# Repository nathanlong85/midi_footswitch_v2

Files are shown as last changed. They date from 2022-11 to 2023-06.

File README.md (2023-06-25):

# MIDI Footswitch v2

## The General Idea

The idea behind this is to be a customizable, solid footswitch for sending and receiving MIDI commands via USB. The following buttons will be implemented:

| Button | Count | Function |
|---|---|---|
| MIDI PC  | 5 | Send a Program Change MIDI command to switch between presets, snapshots, etc. |
| MIDI CC  | 6 | Send a Control Change MIDI command to switch pedals on/off |
| PC StepDown | 1 | Lower the range of PC numbers corresponding with the buttons (e.g. 6-10 to 1-5) |
| PC StepUp | 1 | Raise the range of PC numbers corresponding with the buttons (e.g. 1-5 to 6-10) |
| TempoTap | 1 | This'll probably just end up being a CC button |

The main purpose of this footswitch is to control guitar plugins and presets, specifically in LiveProfessor, but the MIDI out features should all still work fine in another program. Additionally, the footswitch accepts MIDI input. This allows LiveProfessor to send (for example) CC commands when switching presets that will control the button states and have them match up with the plugin states in the preset.

For example, if I switch to a preset that has only a TS808 plugin enabled, the footswitch will first switch all CC buttons off. Then LiveProfessor can send a CC command back to the footswitch to let it know that the button that corresponds with the TS808 should be on.

## Components Used

| Type | Count | Brand | Model | Link | Notes |
|---|---|---|---|---|---|
| Arduino | 1 | Elegoo | Mega2560 | | Chosen for the large number of pins available for buttons |
| Connections Board | 1 | Custom | N/A | N/A | Mostly a convenience to make things as modular as possible. Also used in place of a breadboard for components such as resistors for the LEDs and switches |
| Display | 1 | Teyleten Robot | 2.42" 128x64 SSD1309 OLED | https://a.co/d/j11dIGv | Connected via SPI |
| LED | 14 | N/A | N/A | N/A | Red 5mm |
| LED Holder | 14 | DaierTek | 5MM LED Lamp Holder | https://a.co/d/9saOy9M | |
| SD Card Module | 1 | HiLetgo | Micro SD TF Card Adater Reader Module | https://a.co/d/amf9kn3 | Connected via SPI |
| SD Card | 1 | | | | No need for a high capacity as the only things being stored are configs |
| FootSwitch | 14 | ESUPPORT | Momentary SPST Button | https://a.co/d/4z8qo4Z | |
| TSR Jack | 1 | Kingsing | N/A | https://a.co/d/iaOluce | For the expression pedal |
| Switch | 1 | uxcell | SS12F32-G7 | https://a.co/d/9ZpxkgF | Mini slider switch to change USB modes from Midi to Arduino for uploads |
| USB Jack | 1 | QIANRENON | N/A | https://a.co/d/0RwaqkX | USB-A to USB-C converter and passthrough plate |

Additionally, various electrical components, connector wires, header pins, etc. were used. Those should be available in the KiCad schematics.

## Arduino Pin Assignments

| Number | Purpose | Notes |
|---|---|---|
| 2 | SD Card SPI - CS | Ran out of pins to use near the other SPI pins |
| 22-26 | MIDI PC Button LEDs | Bottom row: buttons 1-5 |
| 27 | StepDown Button LED | Bottom row: button 6 |
| 28 | StepUp Button LED | Bottom row: button 7 |
| 29 | TempoTap Button LED | Bottom row: button 8 |
| 30-35 | MIDI CC Button LEDs | Top row: buttons 1-6 |
| 36-40 | MIDI PC Button Switches | Bottom row: buttons 1-5 |
| 41 | StepDown Button Switch | Bottom row: button 6 |
| 42 | StepUp Button Switch | Bottom row: button 7 |
| 43 | TempoTap Button Switch | Bottom row: button 8 |
| 44-49 | MIDI CC Button Switches | Top row: buttons 1-6 |
| 50 | SPI - MISO | Dictated by Arduino board |
| 51 | SPI - MOSI | Dictated by Arduino board |
| 52 | SPI - SCK | Dictated by Arduino board |
| 53 | Display SPI - CS | Conventional pin for first SPI device |

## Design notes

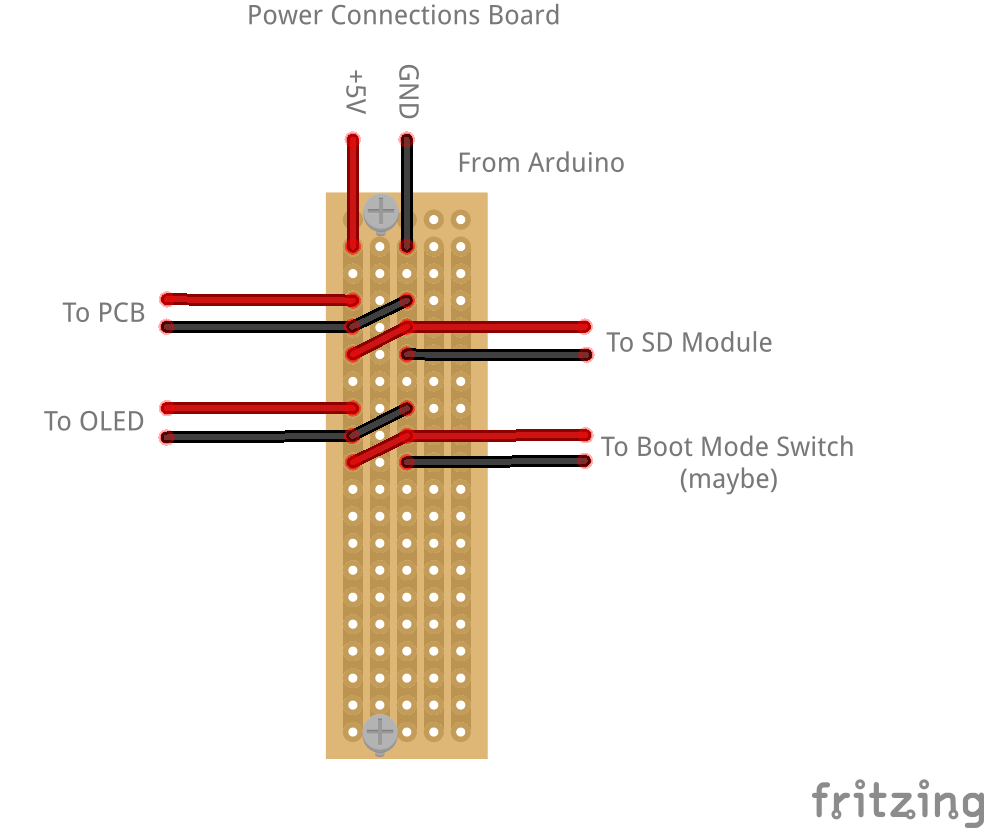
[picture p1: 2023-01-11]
docs/Stripboard Layouts/power_connections.png

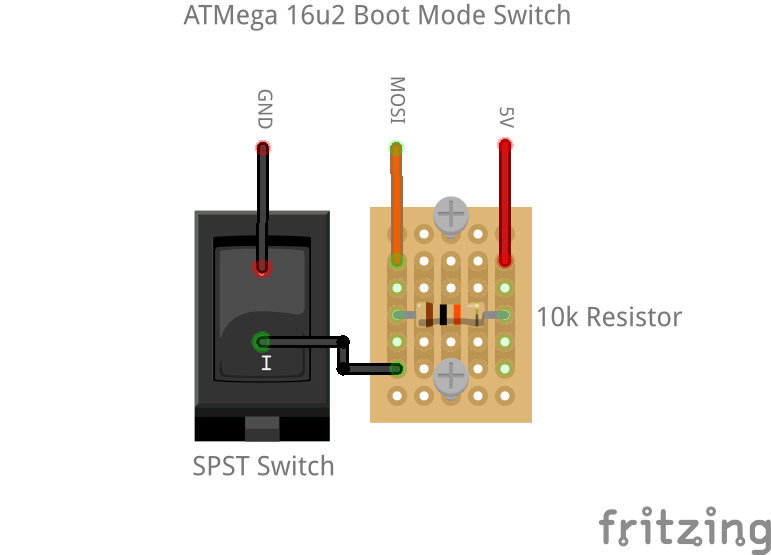
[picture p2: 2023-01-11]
docs/Stripboard Layouts/boot_mode_switch.png

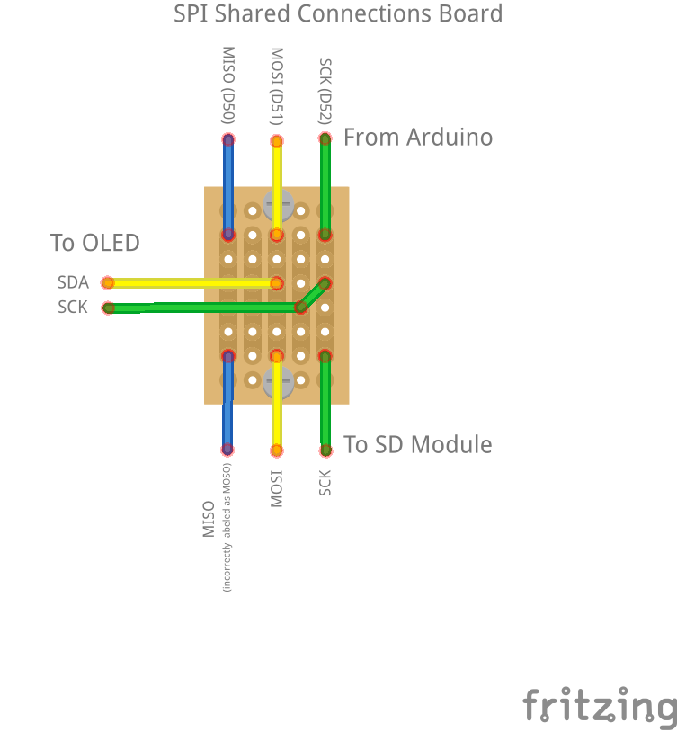
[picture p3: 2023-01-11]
docs/Stripboard Layouts/spi_connections.png

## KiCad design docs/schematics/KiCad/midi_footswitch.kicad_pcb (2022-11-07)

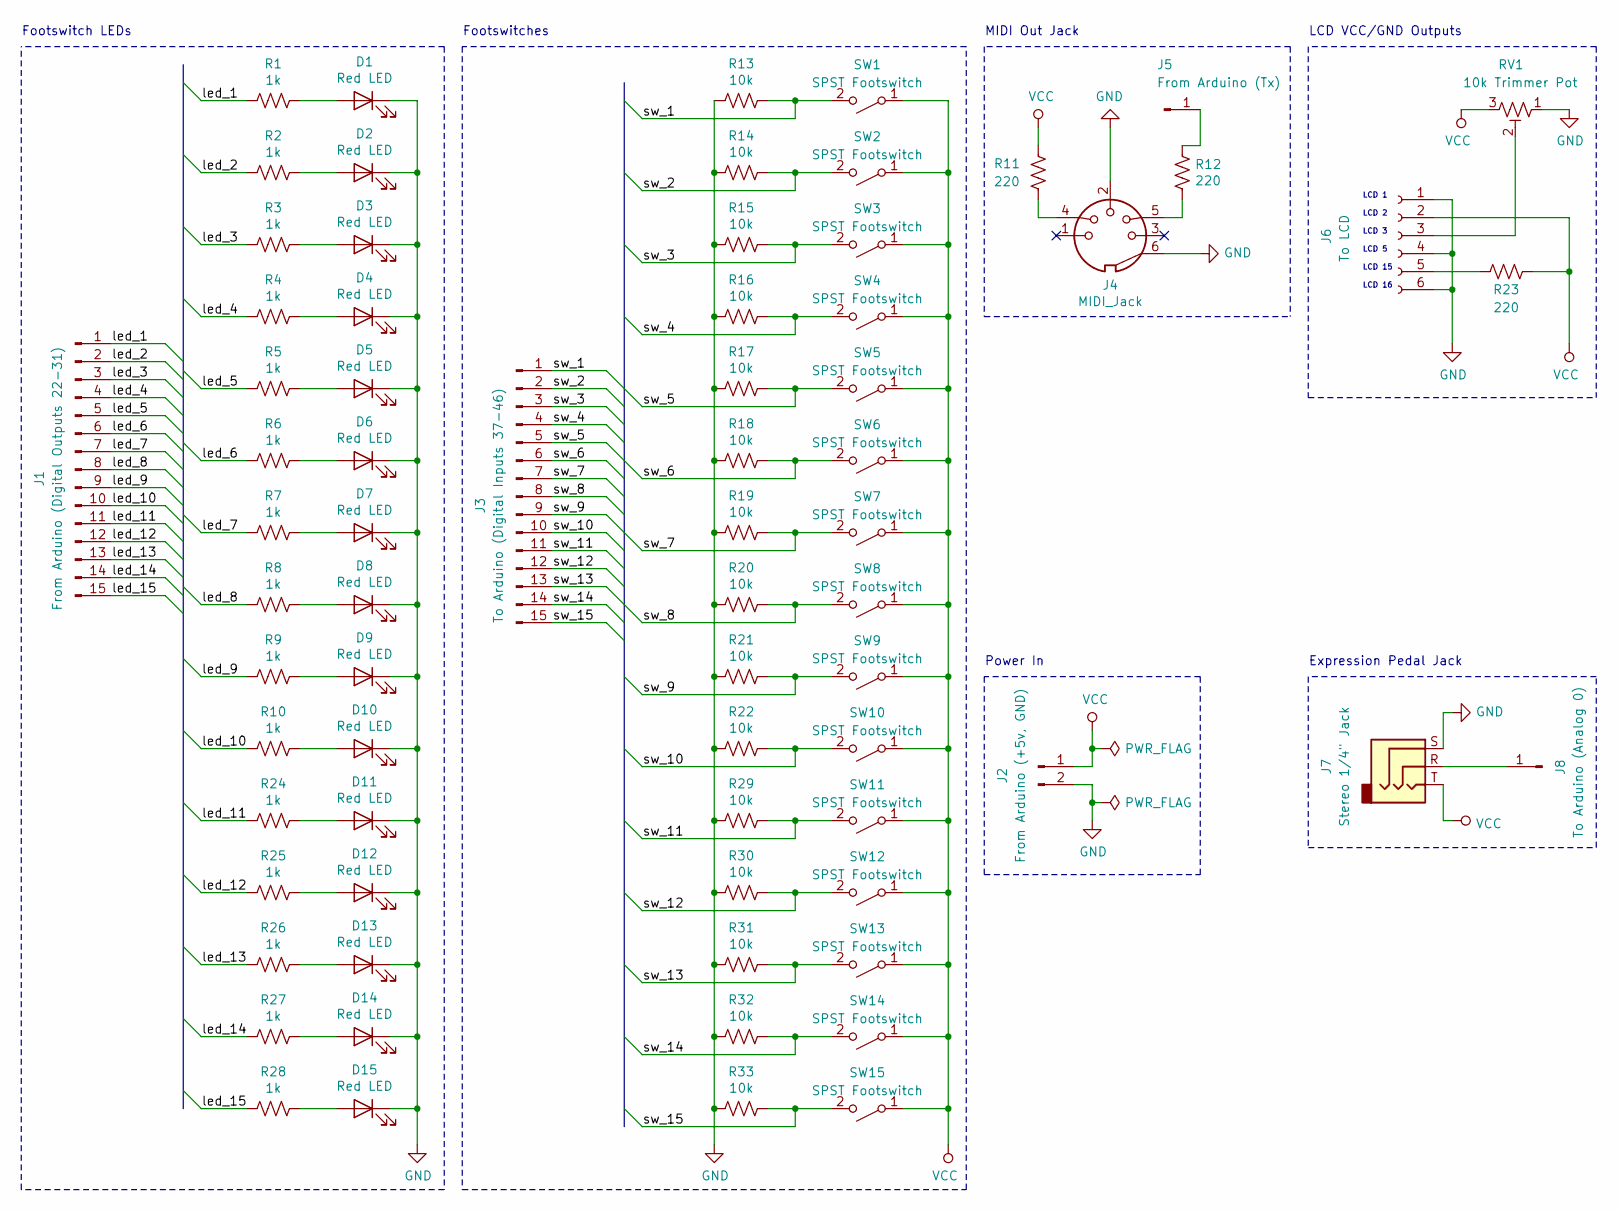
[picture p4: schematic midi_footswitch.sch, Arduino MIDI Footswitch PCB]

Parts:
D1, D2, D3, D4, D5, D6, D7, D8, D9, D10, D11, D12, D13, D14, D15: Red LED; LED_D5.0mm
J1: From Arduino (Digital Outputs 22-31); PinHeader_1x15_P2.54mm_Vertical
J2: From Arduino (+5v, GND); PinHeader_1x02_P2.54mm_Vertical
J3: To Arduino (Digital Inputs 37-46); PinHeader_1x15_P2.54mm_Vertical
J4: MIDI_Jack; midi_jack
J5: From Arduino (Tx); PinHeader_1x01_P2.54mm_Vertical
J6: To LCD; PinHeader_1x06_P2.54mm_Vertical
J7: Stereo 1/4\" Jack; audio_jack_stereo_quarter_inch
J8: To Arduino (Analog 0); PinHeader_1x01_P2.54mm_Vertical
R1, R2, R3, R4, R5, R6, R7, R8, R9, R10, R24, R25, R26, R27, R28: 1k; R_Axial_DIN0207_L6.3mm_D2.5mm_P10.16mm_Horizontal
R11, R12, R23: 220; R_Axial_DIN0207_L6.3mm_D2.5mm_P10.16mm_Horizontal
R13, R14, R15, R16, R17, R18, R19, R20, R21, R22, R29, R30, R31, R32, R33: 10k; R_Axial_DIN0207_L6.3mm_D2.5mm_P10.16mm_Horizontal
RV1: 10k Trimmer Pot; Potentiometer_Runtron_RM-065_Vertical
SW1, SW2, SW3, SW4, SW5, SW6, SW7, SW8, SW9, SW10, SW11, SW12, SW13, SW14, SW15: SPST Footswitch; spst_footswitch

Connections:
/led_1: J1.1, R1.2
/led_2: J1.2, R2.2
/led_3: J1.3, R3.2
/led_4: J1.4, R4.2
/led_5: J1.5, R5.2
/led_6: J1.6, R6.2
/led_7: J1.7, R7.2
/led_8: J1.8, R8.2
/led_9: J1.9, R9.2
/led_10: J1.10, R10.2
/led_11: J1.11, R24.2
/led_12: J1.12, R25.2
/led_13: J1.13, R26.2
/led_14: J1.14, R27.2
/led_15: J1.15, R28.2
/sw_1: J3.1, R13.1, SW1.2 (B)
/sw_2: J3.2, R14.1, SW2.2 (B)
/sw_3: J3.3, R15.1, SW3.2 (B)
/sw_4: J3.4, R16.1, SW4.2 (B)
/sw_5: J3.5, R17.1, SW5.2 (B)
/sw_6: J3.6, R18.1, SW6.2 (B)
/sw_7: J3.7, R19.1, SW7.2 (B)
/sw_8: J3.8, R20.1, SW8.2 (B)
/sw_9: J3.9, R21.1, SW9.2 (B)
/sw_10: J3.10, R22.1, SW10.2 (B)
/sw_11: J3.11, R29.1, SW11.2 (B)
/sw_12: J3.12, R30.1, SW12.2 (B)
/sw_13: J3.13, R31.1, SW13.2 (B)
/sw_14: J3.14, R32.1, SW14.2 (B)
/sw_15: J3.15, R33.1, SW15.2 (B)
GND: D1.1 (K), D2.1 (K), D3.1 (K), D4.1 (K), D5.1 (K), D6.1 (K), D7.1 (K), D8.1 (K), D9.1 (K), D10.1 (K), D11.1 (K), D12.1 (K), D13.1 (K), D14.1 (K), D15.1 (K), J2.2, J4.2, J4.6, J6.1, J6.4, J6.6, J7.S, R13.2, R14.2, R15.2, R16.2, R17.2, R18.2, R19.2, R20.2, R21.2, R22.2, R29.2, R30.2, R31.2, R32.2, R33.2, RV1.1
unnamed: D1.2 (A), R1.1
unnamed: D2.2 (A), R2.1
unnamed: D3.2 (A), R3.1
unnamed: D4.2 (A), R4.1
unnamed: D5.2 (A), R5.1
unnamed: D6.2 (A), R6.1
unnamed: D7.2 (A), R7.1
unnamed: D8.2 (A), R8.1
unnamed: D9.2 (A), R9.1
unnamed: D10.2 (A), R10.1
unnamed: D11.2 (A), R24.1
unnamed: D12.2 (A), R25.1
unnamed: D13.2 (A), R26.1
unnamed: D14.2 (A), R27.1
unnamed: D15.2 (A), R28.1
unnamed: J4.4, R11.2
unnamed: J4.5, R12.2
unnamed: J5.1, R12.1
unnamed: J6.3, RV1.2
unnamed: J6.5, R23.2
unnamed: J7.R, J8.1
VCC: J2.1, J6.2, J7.T, R11.1, R23.1, RV1.3, SW1.1 (A), SW2.1 (A), SW3.1 (A), SW4.1 (A), SW5.1 (A), SW6.1 (A), SW7.1 (A), SW8.1 (A), SW9.1 (A), SW10.1 (A), SW11.1 (A), SW12.1 (A), SW13.1 (A), SW14.1 (A), SW15.1 (A)

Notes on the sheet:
Footswitch LEDs
Footswitches
MIDI Out Jack
LCD VCC/GND Outputs
Power In
LCD 1
LCD 16
LCD 15
LCD 5
LCD 3
LCD 2
Expression Pedal Jack

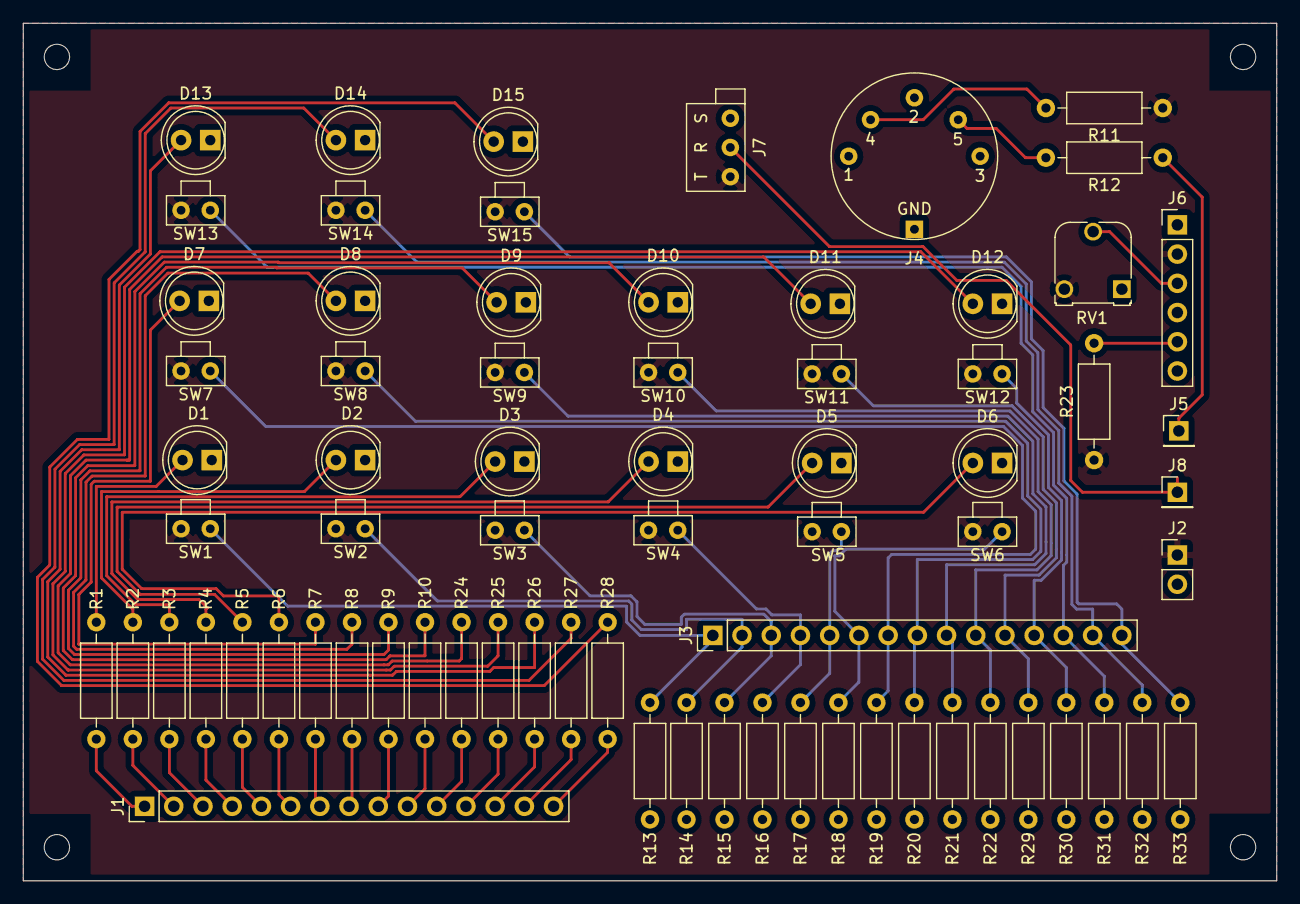
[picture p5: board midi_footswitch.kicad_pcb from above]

Board: 2 copper layers, 109.0 x 74.5 mm, 72 parts (0 on the bottom side), 53 nets.

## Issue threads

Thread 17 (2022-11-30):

Find a way to avoid using the Arduino and ISP USB ports directly

nathanlong85, 2022-11-30:
Up until now, the plan has been to butt the Arduino and USBTinyISP boards right up against the enclosure to access their USB ports. Ideally though, they wouldn't be directly exposed to avoid damaging them. Additionally, it'd be nice to have USB-C ports instead of big chunky USB-B.

**Bonus points if I can wire it up so that there's only a single USB port instead of two using a switch or something.**

The ideal solution would be a very short cable with USB-B on one end and a female, mountable USB-C jack on the other end that I could mount to the inside of the enclosure. That seems very hard to find though.

Another solution could be using a short USB-B cable and wiring it up to a USB-C breakout board with mounting holes (like [this](https://a.co/d/3DzCjk2)). That could be mounted to a block of wood, which could then be butted up against the inside of the enclosure. It'd also make it easy to attach to an on/on switch if I was dealing directly with wires from the USB cables...

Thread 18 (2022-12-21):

Create USB Switch Board

nathanlong85, 2022-12-21:
Create a board with Veroboard to wire up a switch for changing USB modes. It should just be a two-contact SPST switch. When off, the USB firmware is in MIDI mode. When on, it's in Arduino mode and can upload firmware and use serial console.

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

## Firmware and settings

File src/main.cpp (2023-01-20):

#include <Arduino.h>

// C++ STL implementation for Arduino
#include <ArduinoSTL.h>
#include <vector>

// Private
#include <PrivateMidi.h>
#include <Buttons.h>
#include <Oled.h>

void setup()
{
  // Temp dev button assignments
  ProgramChangeButton::registerNew(45, 30);        // Row 1 - Button 1
  ProgramChangeButton::registerNew(46, 31);        // Row 1 - Button 2
  ProgramChangeStepButton::registerNew(47, 32, 1); // Row 1 - Button 7 - Step Up
  // ControlChangeButton::registerNew(47, 32, 22); // Row 2 - Button 11

  // Initialize the PC buttons (switchPin, ledPin)
  // ProgramChangeButton::registerNew(36, 22); // Row 1 - Button 1
  // ProgramChangeButton::registerNew(37, 23); // Row 1 - Button 2
  // ProgramChangeButton::registerNew(38, 24); // Row 1 - Button 3
  // ProgramChangeButton::registerNew(39, 25); // Row 1 - Button 4
  // ProgramChangeButton::registerNew(40, 26); // Row 1 - Button 5

  // Initialize the CC buttons (switchPin, ledPin, ccNumber)
  // ControlChangeButton::registerNew(45, 30, 20); // Row 2 - Button  9
  // ControlChangeButton::registerNew(46, 31, 21); // Row 2 - Button 10
  // ControlChangeButton::registerNew(47, 32, 22); // Row 2 - Button 11
  // ControlChangeButton::registerNew(48, 33, 23); // Row 2 - Button 12
  // ControlChangeButton::registerNew(49, 34, 24); // Row 2 - Button 13
  // ControlChangeButton::registerNew(50, 35, 25); // Row 2 - Button 14

  // Initialize the PC Step buttons
  // ProgramChangeStepButton::registerNew(41, 27, -1); // Row 1 - Button 6 - Step Down
  // ProgramChangeStepButton::registerNew(42, 28, 1);  // Row 1 - Button 7 - Step Up

  // Start listening to MIDI on channel 1 and set callbacks to
  // listen for specific incoming MIDI messages
  PrivateMidi::MIDI.begin(1);

  // Initialize the OLED display
  Oled::getInstance()->displayInit(false);
  Oled::getInstance()->addLogLine("MIDI controller ready");
}

void loop()
{
  // Check for incoming MIDI messages
  PrivateMidi::MIDI.read();

  // Check for any pressed CC buttons
  ControlChangeButton::read();

  // Check for any pressed PC buttons
  ProgramChangeButton::read();

  // Check for a pressed PC StepUp or PC StepDown button
  // pcStepDownButton.
}

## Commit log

2022-11-07 Add .gitignore
    [breadboard.fzz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]
2022-11-10 Clearing old files
    [breadboard.fzz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]
2022-11-10 Add new files
    [breadboard.fzz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]
2022-11-22 Add CC buttons and features
    [breadboard.fzz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]
2023-01-11 Add OLED, add CC logging
    [boot_mode_switch.fzz, power_connections.fzz, spi_connections.fzz]
2023-01-11 Minor tweaks after testing on actual Arduino
2023-01-20 Added PC buttons
